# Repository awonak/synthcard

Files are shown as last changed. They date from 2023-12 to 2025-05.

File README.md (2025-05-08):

# SynthCard

Synth Card for Adam Wonak

This synthcard is a circuit inspired by [Hagiwo's](https://www.youtube.com/@HAGIWO) SyncLFO and Bezier Curve, and the [Modulove](https://modulove.io/) MVMNT. I chose this design because of the seemingly endless creative firmware scripts I have written for the [Modulove Sync LFO](https://awonak.github.io/HagiwoModulove/synclfo/), so I wanted to make a business card to highlight this circuit design with some fun tweaks.

This is an iteration of the [SynthCard.com](https://synthcard.com) community from [Benjie Jiao](https://github.com/benjiao). 

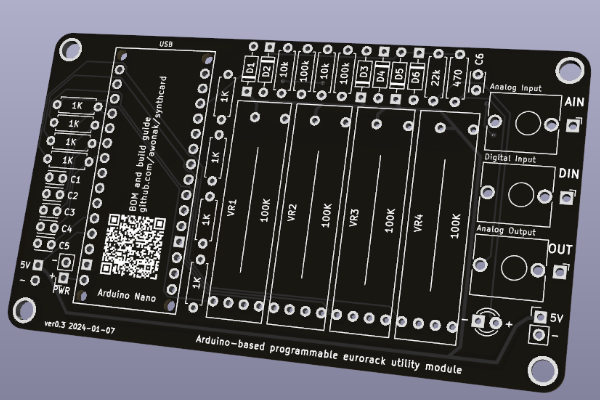
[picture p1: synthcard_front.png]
SynthCard front


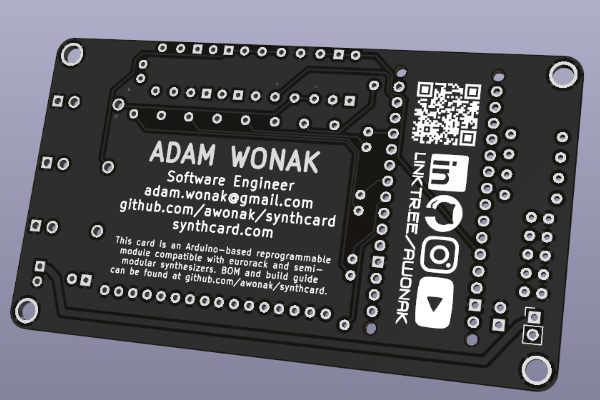
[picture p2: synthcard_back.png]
SynthCard back


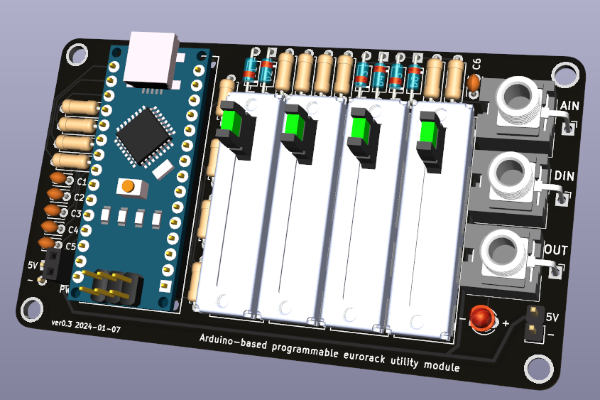
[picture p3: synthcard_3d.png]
SynthCard 3D


## Demo Videos

4 Step Sequencer - https://youtu.be/5_vGYVA8IQ8

ADSR - https://youtu.be/wfQtB7HLKf4

## Synth Card Built by Friends 

[[@benjiaomodular](https://www.youtube.com/@benjiaomodular)] - https://youtube.com/shorts/xnUs8CACG_8

[[@bildpunkt](http://on.soundcloud.com/M9RUxw48PaAXDL477)] - https://youtu.be/3e_gjm9oc40

## Bill of Materials

To assist with assembly, you can use the interactive [ibom.html page](https://htmlpreview.github.io/?https://github.com/awonak/synthcard/blob/main/hardware/bom/ibom.html) to view a part placement guide.

| Reference(s) | Qty | Value | Supplier Link |
|-|-|-|-|
| C1, C2, C3, C4, C5 | 5 | 0.1uF Capacitor  | https://www.mouser.com/ProductDetail/594-K104M15X7RF53L2 |
| C6 | 1 | 4.7uF Capacitor | https://www.mouser.com/ProductDetail/810-FG14X5R1H475KRT6 |
| D1, D2, D3, D4, D5, D6 | 6 | 1N5817 Schottky Diode | https://www.mouser.com/ProductDetail/833-1N5817-TP |
| D7 | 1 | 3MM LED | https://www.mouser.com/ProductDetail/604-WP3A8ID |
| R1, R2, R3, R4 | 4 | 1K Resistor | https://www.mouser.com/ProductDetail/660-MF1-4DCT52R1001F |
| R11, R12, R13, R14 | 4 | 1K Resistor (LED Brightness) | https://www.mouser.com/ProductDetail/660-MF1-4DCT52R1001F |
| R5, R7 | 2 | 10k Resistor | https://www.mouser.com/ProductDetail/660-MF1-4DCT52R1002F |
| R6, R8 | 2 | 100k Resistor | https://www.mouser.com/ProductDetail/660-MF1-4D52R1003F |
| R9 | 1 | 22k Resistor | https://www.mouser.com/ProductDetail/660-MF1-4DCT52R2202F |
| R10 | 1 | 470 Resistor | https://www.mouser.com/ProductDetail/660-MF1-4DCT52R4700F |
| VR1, VR2, VR3, VR4 | 4 | 20MM Slide Potentiometer 100K | https://www.mouser.com/ProductDetail/652-PTL20-15R0-104B1 |
| J3, J4, J5 | 1 | Thonkiconn 3.5mm Mono Jack | https://www.thonk.co.uk/shop/thonkiconn/ |
| A1 | 1 | Arduino Nano | [https://www.amazon.com/...](https://www.amazon.com/LAFVIN-Board-ATmega328P-Micro-Controller-Arduino/dp/B07G99NNXL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) |

## Pinout

| Arduino Pin | Function |
|-|-|
| A0 | Slider 1 Input |
| A1 | Slider 2 Input |
| A2 | Slider 3 Input |
| A3 | Slider 4 Input |
| A7 | Analog Input |
| D3 | Slider 4 LED |
| D5 | Slider 3 LED |
| D6 | Slider 2 LED |
| D9 | Slider 1 LED |
| D10 | Digital Output |
| D11 | Digital Input |

## Code Example

The most basic program we can write for the Synth Card is a Blink program. Using the pin guide above, we can see the digital output is `D10` which has an LED connected to the circuit. We can use this pin to blink the LED. 

```cpp
#define CV_OUT 10  // CV Output with LED

void setup() {
  pinMode(CV_OUT, OUTPUT);
}

void loop() {
  digitalWrite(CV_OUT, HIGH);
  delay(500);
  digitalWrite(CV_OUT, LOW);
  delay(500);
}
```

To test out all of the inputs, outputs, and LEDs, you can flash the [HardwareTest](firmware/HardwareTest/HardwareTest.ino) script.

To see additional example firmware scripts, head over to [firmware](firmware/).

## Hardware Revision History

| Revision | Date | Notes
|-|-|-|
| ver0.3 | 2024-01-07 | - Change: minor silkscreen updates<br> - Change: made 5v trace larger
| ver0.2 | 2023-12-28 | - Fix: CV Output circuit was backwards<br> - Change: Rename capacitor footprint values<br> - Change: Improved LED footprint values<br> - Change: Add linktr.ee and social logos 
| ver0.1 | 2023-12-18 | Initial release

## Enclosure

* Case: [OnShape 3D printer case design](https://cad.onshape.com/documents/56a3cdf5a05401551b0a6543/v/da0e57abf21331cdf97fa6e6/e/f128ee10c6516a251dc2fe2a)
* Cover: [OnShape 3D printer cover design](https://cad.onshape.com/documents/eee74bc148d4d859dd74c709/w/c0c5180a8fda910a15efede6/e/bb4b46e599de372330158219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) (Designed by [BbartokK](https://bbartokk.bandcamp.com/))

## Buy a SynthCard Kit



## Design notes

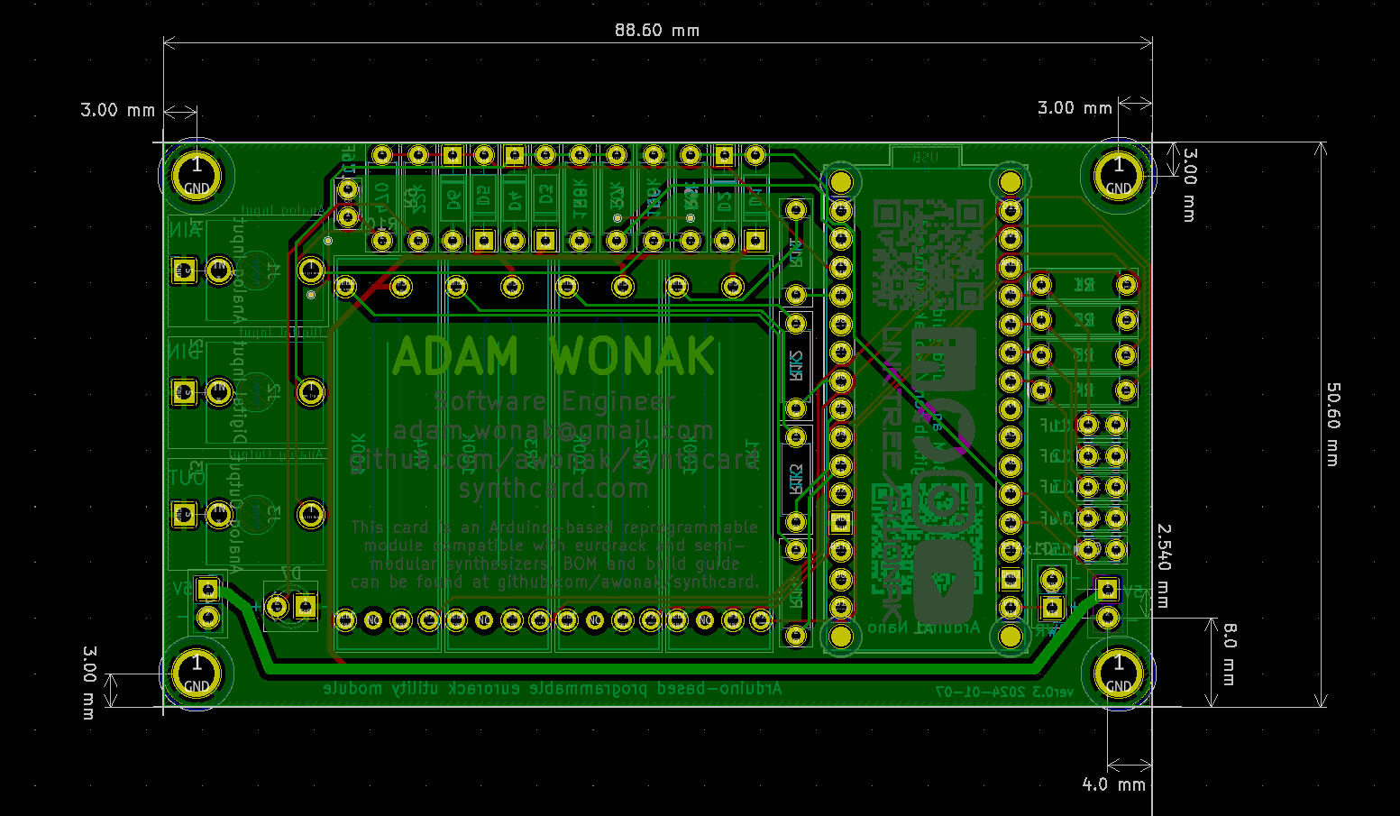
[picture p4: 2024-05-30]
hardware/pcb_view.png

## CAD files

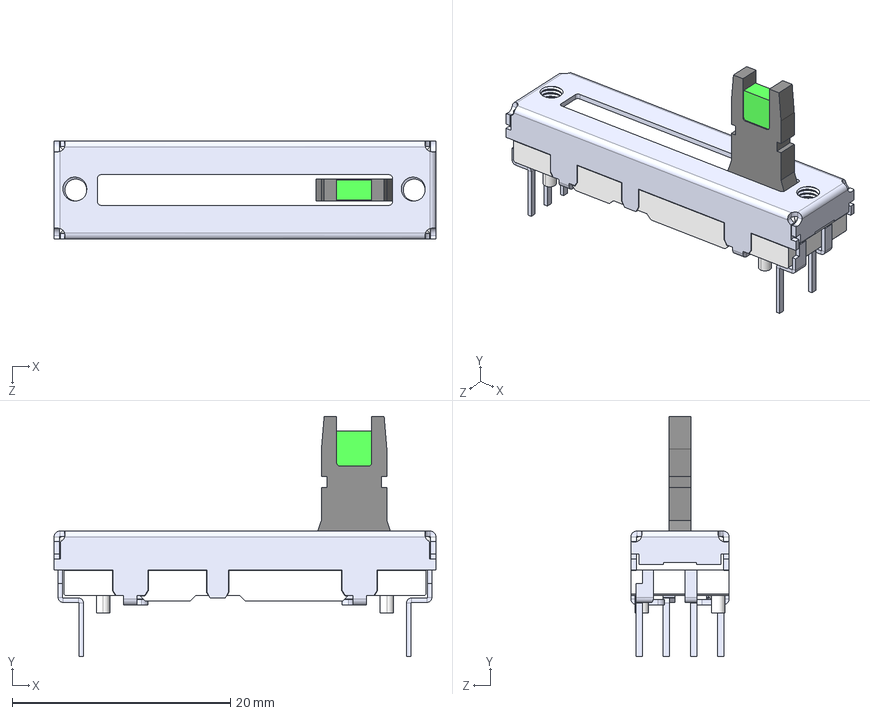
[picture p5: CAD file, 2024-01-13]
hardware/models/PTL20-10R1-102B2.STEP
35.0 x 22.0 x 9.00 mm

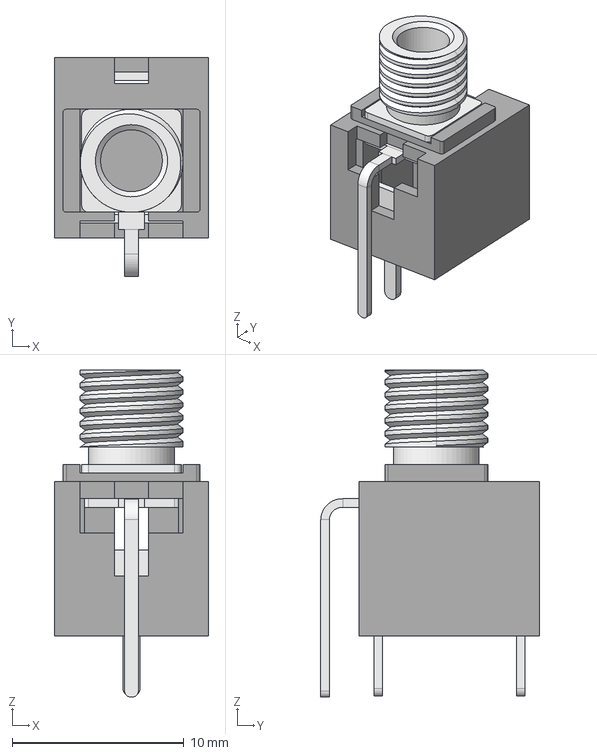
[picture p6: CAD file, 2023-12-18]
hardware/models/PJ398SM.step
9.00 x 12.7 x 19.1 mm

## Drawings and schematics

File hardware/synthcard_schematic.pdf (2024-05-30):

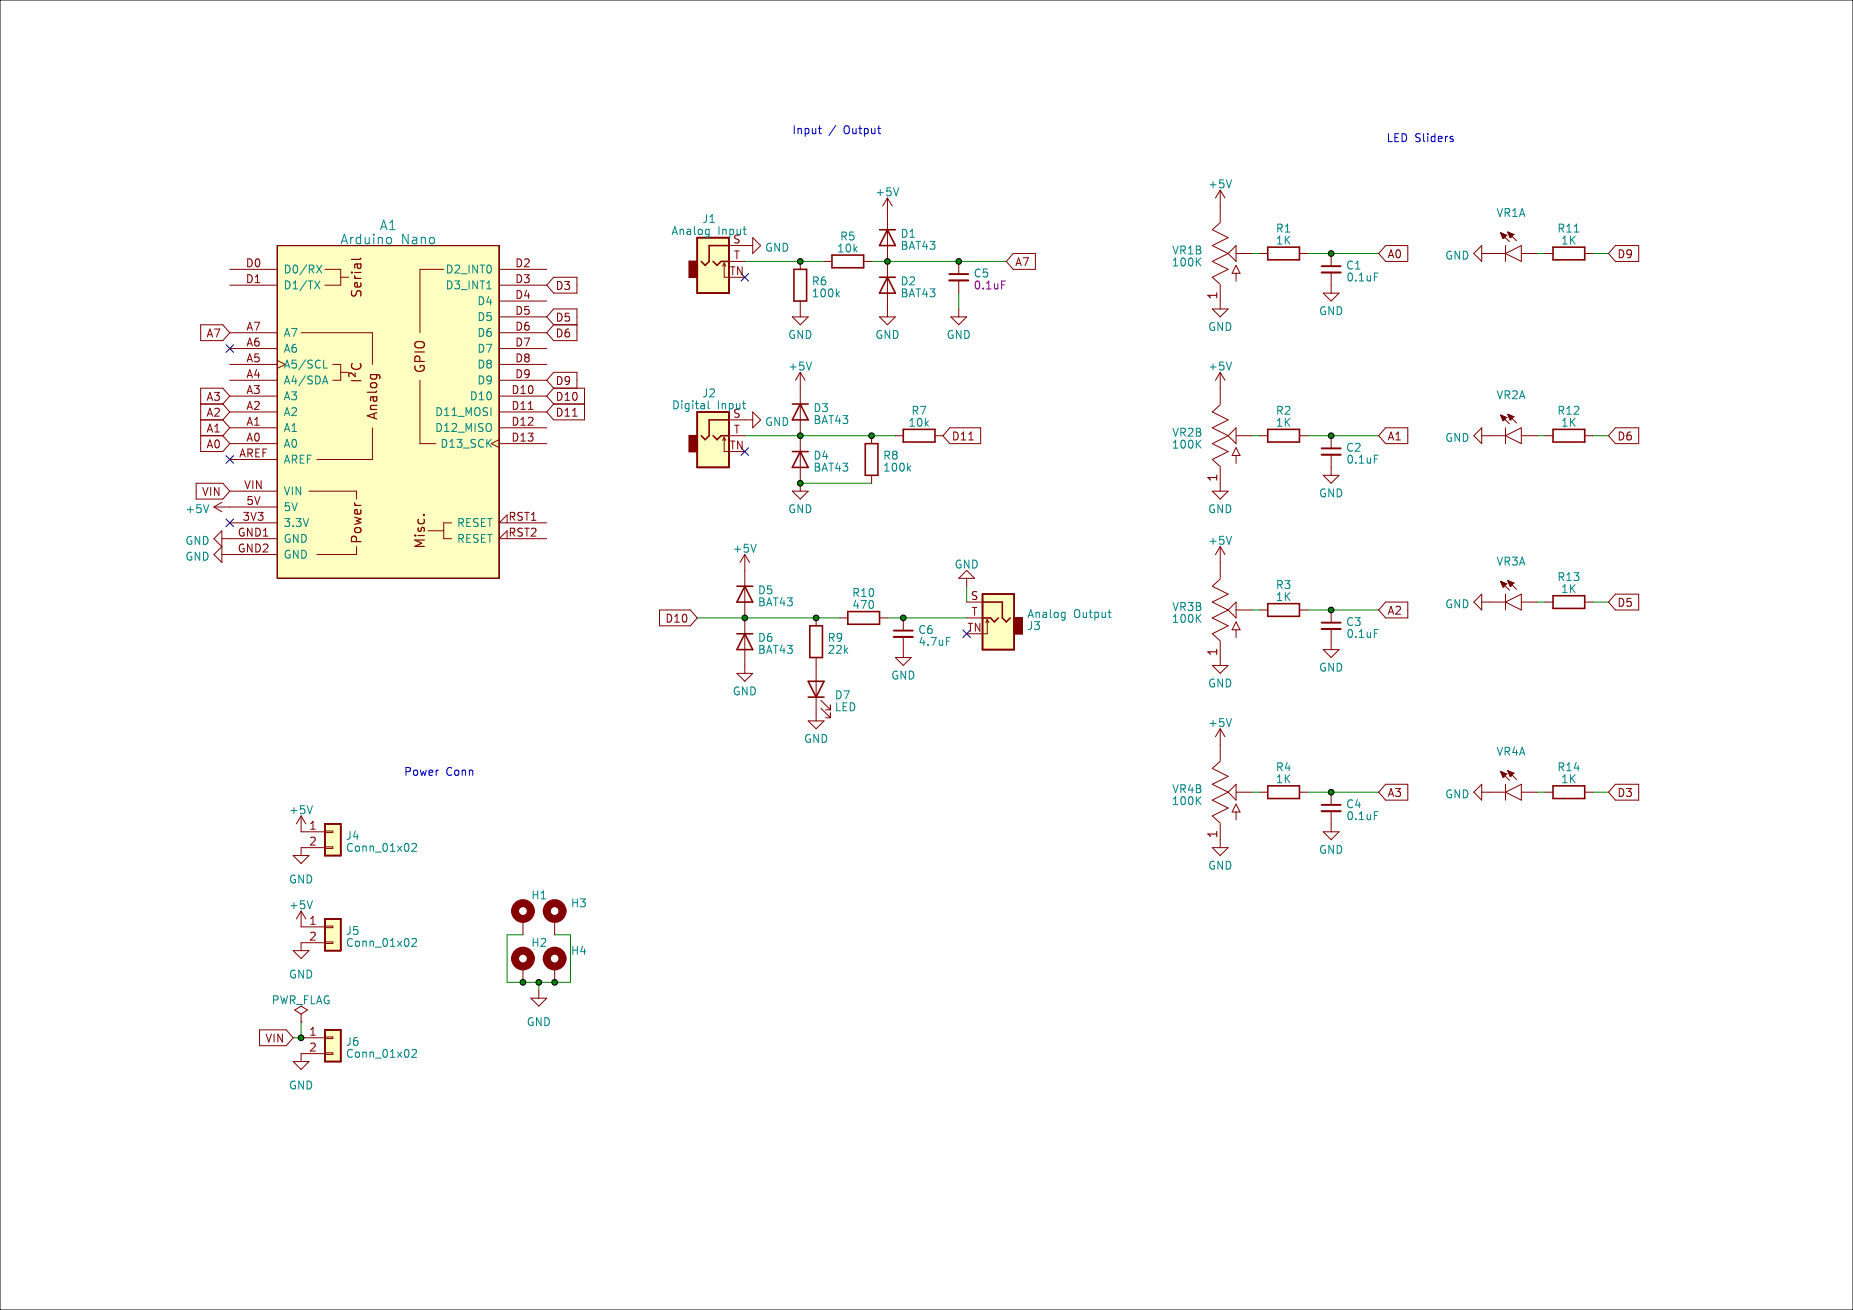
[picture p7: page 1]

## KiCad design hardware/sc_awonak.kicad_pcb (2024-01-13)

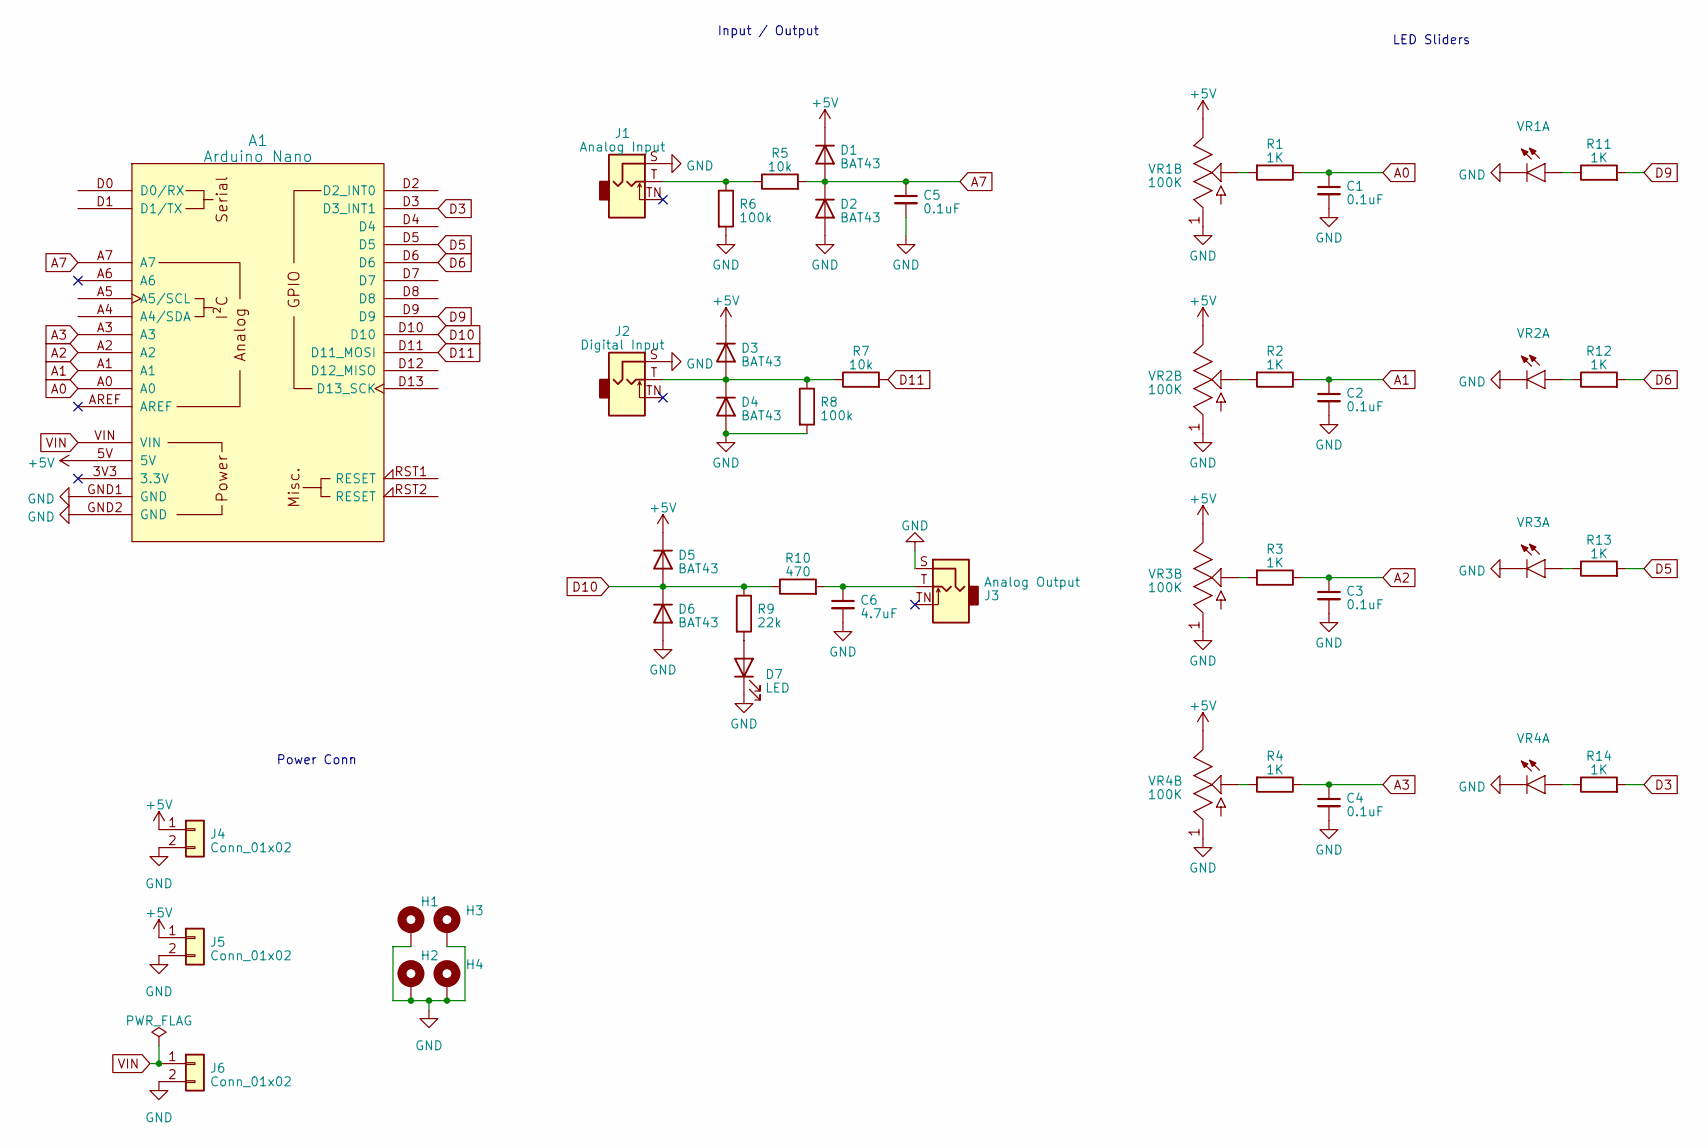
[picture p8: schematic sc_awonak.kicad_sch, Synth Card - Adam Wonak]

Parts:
A1: Arduino Nano; Arduino_Nano_Socket
C1, C2, C3, C4, C5: 0.1uF; C_Disc_D3.0mm_W2.0mm_P2.50mm
C6: 4.7uF; C_Disc_D3.0mm_W2.0mm_P2.50mm
D1, D2, D3, D4, D5, D6: BAT43; D_DO-35_SOD27_P7.62mm_Horizontal
D7: LED; LED_D3.0mm
H1, H2, H3, H4: MountingHole_Pad; MountingHole_3.2mm_M3_Pad
J1: Analog Input; Jack_3.5mm_QingPu_WQP-PJ398SM_Vertical_CircularHoles
J2: Digital Input; Jack_3.5mm_QingPu_WQP-PJ398SM_Vertical_CircularHoles
J3: Analog Output; Jack_3.5mm_QingPu_WQP-PJ398SM_Vertical_CircularHoles
J4, J5, J6: Conn_01x02; PinHeader_1x02_P2.54mm_Horizontal
R1, R2, R3, R4, R11, R12, R13, R14: 1K; R_Axial_DIN0207_L6.3mm_D2.5mm_P7.62mm_Horizontal
R5, R7: 10k; R_Axial_DIN0207_L6.3mm_D2.5mm_P7.62mm_Horizontal
R6, R8: 100k; R_Axial_DIN0207_L6.3mm_D2.5mm_P7.62mm_Horizontal
R9: 22k; R_Axial_DIN0207_L6.3mm_D2.5mm_P7.62mm_Horizontal
R10: 470; R_Axial_DIN0207_L6.3mm_D2.5mm_P7.62mm_Horizontal
VR1, VR2, VR3, VR4: 100K; Pot_Slider_LED_20mm_RA2045F

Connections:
+5V: A1.5V, D1.1 (K), D3.1 (K), D5.1 (K), J4.1, J5.1, VR1.P3 (3), VR2.P3 (3), VR3.P3 (3), VR4.P3 (3)
A0: A1.A0, C1.1, R1.1
A1: A1.A1, C2.1, R2.1
A2: A1.A2, C3.1, R3.1
A3: A1.A3, C4.1, R4.1
A7: A1.A7, C5.1, D1.2 (A), D2.1 (K), R5.2
D3: A1.D3 (D3_INT1), R14.2
D5: A1.D5, R13.2
D6: A1.D6, R12.2
D9: A1.D9, R11.2
D10: A1.D10, D5.2 (A), D6.1 (K), R9.1, R10.1
D11: A1.D11 (D11_MOSI), R7.2
GND: A1.GND1 (GND), A1.GND2 (GND), C1.2, C2.2, C3.2, C4.2, C5.2, C6.2, D2.2 (A), D4.2 (A), D6.2 (A), D7.1 (K), H1.1, H2.1, H3.1, H4.1, J1.S, J2.S, J3.S, J4.2, J5.2, J6.2, R6.2, R8.2, VR1.LEDC (C), VR1.P1 (1), VR2.LEDC (C), VR2.P1 (1), VR3.LEDC (C), VR3.P1 (1), VR4.LEDC (C), VR4.P1 (1)
unnamed: C6.1, J3.T, R10.2
unnamed: D3.2 (A), D4.1 (K), J2.T, R7.1, R8.1
unnamed: D7.2 (A), R9.2
unnamed: J1.T, R5.1, R6.1
unnamed: R11.1, VR1.LEDA (A)
unnamed: R1.2, VR1.P2 (2)
unnamed: R12.1, VR2.LEDA (A)
unnamed: R2.2, VR2.P2 (2)
unnamed: R13.1, VR3.LEDA (A)
unnamed: R3.2, VR3.P2 (2)
unnamed: R14.1, VR4.LEDA (A)
unnamed: R4.2, VR4.P2 (2)
VIN: A1.VIN, J6.1

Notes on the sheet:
Input / Output
LED Sliders
Power Conn

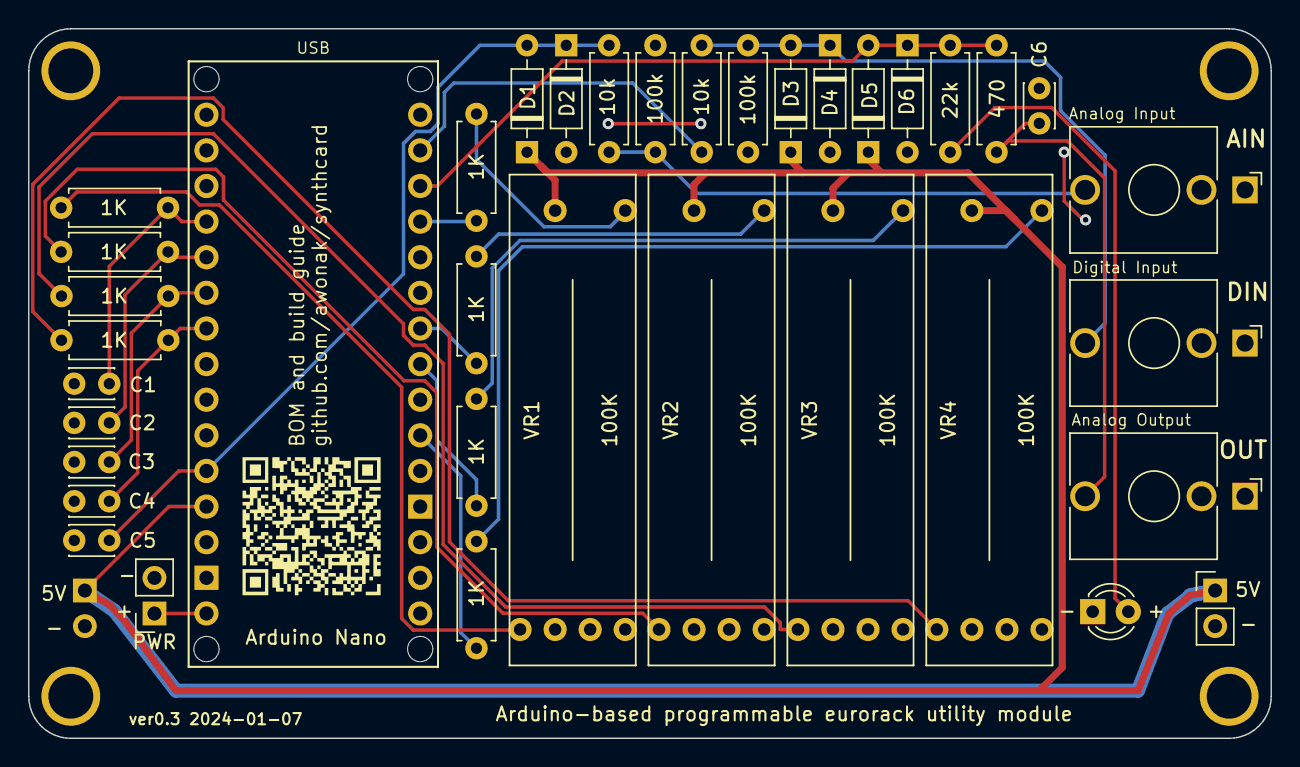
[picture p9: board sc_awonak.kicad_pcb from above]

Board: 2 copper layers, 88.6 x 50.6 mm, 42 parts (1 on the bottom side), 26 nets.

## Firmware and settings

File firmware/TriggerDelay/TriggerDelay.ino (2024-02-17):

// GPIO Pin mapping.
#define P1 A0  // Trigger Delay
#define P2 A1  // Attack Slope
#define P3 A2  // Gate Duration
#define P4 A3  // Release Slope
#define SLIDER_COUNT 4

#define LED1 9  // Slider LED 1
#define LED2 6  // Slider LED 2
#define LED3 5  // Slider LED 3
#define LED4 3  // Slider LED 4

#define ANALOG_IN 21   // Analog Input
#define DIGITAL_IN 11  // Trigger Input to advance step
#define CV_OUT 10      // CV Output for current step

// Slider & LED pin arrays to support looping over led sliders.
const uint8_t SLIDER_PIN[SLIDER_COUNT] = {P1, P2, P3, P4};
const uint8_t LED_PIN[SLIDER_COUNT] = {LED1, LED2, LED3, LED4};

// Conversion calculations: Arduino 5v pin will only output 4.6v when powered by
// USB.
const float VREF = 4.6 / 1023.0;

// Global state variables.
uint8_t din = 0;  // Digital input read value.
uint8_t old_din = 0;
int slider[SLIDER_COUNT];  // Hold the current slider value in an array of
                           // sliders.
float R;                   // R holds the linear to exponential conversion factor value.

enum Stage {
    DELAY,
    ATTACK,
    GATE,
    RELEASE,
    WAIT,
};
Stage stage = WAIT;

// Script state.
unsigned long trig_start;
int trig_delay;
int trig_duration;
int attack_slope;
int release_slope;
int attack_count;
int release_count;
int counter;
int output;

void setup() {
    pinMode(ANALOG_IN, INPUT);
    pinMode(DIGITAL_IN, INPUT);
    pinMode(CV_OUT, OUTPUT);
    pinMode(P1, INPUT);
    pinMode(P2, INPUT);
    pinMode(P3, INPUT);
    pinMode(P4, INPUT);
    pinMode(LED1, OUTPUT);
    pinMode(LED2, OUTPUT);
    pinMode(LED3, OUTPUT);
    pinMode(LED4, OUTPUT);

    // Register setting for high frequency PWM.
    TCCR1A = 0b00100001;
    TCCR1B = 0b00100001;

    // Calculate the linear to exponential R value (only needs to be done once at setup).
    R = (1023 * log10(2)) / (log10(255));
}

void loop() {
    // Read all inputs.
    old_din = din;
    din = digitalRead(DIGITAL_IN);
    for (int i = 0; i < SLIDER_COUNT; i++) {
        slider[i] = analogRead(SLIDER_PIN[i]);
    }

    // Set LED Brightness.
    for (int i = 0; i < SLIDER_COUNT; i++) {
        analogWrite(LED_PIN[i], brightness(slider[i]));
    }

    // Detect if a new trigger has been received.
    if (old_din == 0 && din == 1) {
        // Read the trigger delay and duration.
        trig_delay = map(slider[0], 0, 1023, 0, 2000);
        trig_duration = map(slider[2], 0, 1023, 20, 2000);
        trig_start = millis();

        // Calculate the exponential slope value.
        attack_count = slider[1];
        release_count = slider[3];
        attack_slope = (attack_count * log10(2)) / log10(255);
        release_slope = (release_count * log10(2)) / log10(255);

        stage = DELAY;
        output = 0;
        counter = 1;
    }

    switch (stage) {
        case DELAY:
            if (millis() > trig_start + trig_delay) {
                stage = ATTACK;
            }
            break;
        case ATTACK:
            if (counter >= attack_count) {
                stage = GATE;
                trig_start = millis();
                counter = release_count;
            } else {
                output = min(pow(2, (float(counter) / float(attack_slope))), 255);
                counter = min(counter++, attack_count);
            }
            break;
        case GATE:
            output = 255;
            if (millis() > trig_start + trig_duration) {
                stage = RELEASE;
            }
            break;
        case RELEASE:
            if (counter == 0) {
                stage = WAIT;
                output = 0;
            } else {
                output = min(pow(2, float(counter) / float(release_slope)), 255);
                if (counter > 0) counter--;
            }
            break;
        case WAIT:
            break;
    }

    // Set output voltage.
    analogWrite(CV_OUT, output);
}

// Convert a linear value to its exponential compliment for led visual correction.
int brightness(int v) { return (v > 32) ? pow(2, (v / R)) : 0; }

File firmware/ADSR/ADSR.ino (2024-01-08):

// GPIO Pin mapping.
#define S1 A0  // Slider Potentiometer 1
#define S2 A1  // Slider Potentiometer 2
#define S3 A2  // Slider Potentiometer 3
#define S4 A3  // Slider Potentiometer 4
#define SLIDER_COUNT 4

#define LED1 9  // Slider LED 1
#define LED2 6  // Slider LED 2
#define LED3 5  // Slider LED 3
#define LED4 3  // Slider LED 4

#define ANALOG_IN A7   // Analog Input
#define DIGITAL_IN 11  // Trigger Input to advance step
#define CV_OUT 10      // CV Output for current step

// Slider & LED pin arrays to support looping over led sliders.
const uint8_t SLIDER_PIN[SLIDER_COUNT] = {S1, S2, S3, S4};
const uint8_t LED_PIN[SLIDER_COUNT] = {LED1, LED2, LED3, LED4};

// Conversion calculations: Arduino 5v pin will only output 4.6v when powered by
// USB.
const float VREF = 4.6 / 1023.0;

// Global state variables.
int ain = 0;  // Raw cv read from pot for current step
int old_ain = 0;
uint8_t din = 0;  // Digital input read value.
uint8_t old_din = 0;
int slider[SLIDER_COUNT];  // Hold the current slider value in an array of
                           // sliders.
float R;  // R holds the linear to exponential conversion factor value.

// Script state variables.
const byte top = 255;  // Envelope state max value
byte val = 0;          // Envelope state value
int time = 0;          // Envelope delay time between incremental change
int sustain = 0;       // Sustain value;

enum Stage { ATTACK, DECAY, SUSTAIN, RELEASE };
Stage stage = ATTACK;

void setup() {
  pinMode(ANALOG_IN, INPUT);
  pinMode(DIGITAL_IN, INPUT);
  pinMode(CV_OUT, OUTPUT);
  pinMode(S1, INPUT);
  pinMode(S2, INPUT);
  pinMode(S3, INPUT);
  pinMode(S4, INPUT);
  pinMode(LED1, OUTPUT);
  pinMode(LED2, OUTPUT);
  pinMode(LED3, OUTPUT);
  pinMode(LED4, OUTPUT);

  // Register setting for high frequency PWM.
  TCCR1A = 0b00100001;
  TCCR1B = 0b00100001;

  // Calculate the R variable (only needs to be done once at setup).
  R = (1023 * log10(2)) / (log10(255));

  delay(100);
}

void loop() {
  // Check gate input.
  old_din = din;
  din = digitalRead(DIGITAL_IN);

  // Detect if gate has just opened and begin envelope attack.
  if (old_din == 0 && din == 1) {
    stage = ATTACK;
    val = 0;
  }

  // Detect if gate has just closed and begin the release envelope.
  if (old_din == 1 && din == 0) {
    stage = RELEASE;
  }

  // Advance the cv value for the current envelope stage according to the
  // related stage knob position.
  switch (stage) {
    case ATTACK:
      // At minimum attack levels, traverse the curve at a faster rate than
      // default.
      val += analogRead(S1) == 0 ? min(top - val, 10) : 1;

      if (val >= top) {
        stage = DECAY;
      }
      break;

    case DECAY:
      // Decrease the envelope value if it's still falling.
      if (val > 0) {
        // At minimum release levels, traverse the curve at a faster rate than
        // default.
        val -= analogRead(S2) == 0 ? min(val, 10) : 1;
      }

      // Check if the falling decay envelope has reached sustain level.
      sustain = min(map(analogRead(S3), 0, 1023, 0, top), val);
      if (val <= sustain) {
        stage = SUSTAIN;
      }
      break;

    case SUSTAIN:
      val = map(analogRead(S3), 0, 1023, 0, top);
      break;

    case RELEASE:
      // Decrease the envelope value if it's still falling.
      if (val > 0) {
        // At minimum release levels, traverse the curve at a faster rate than
        // default.
        val -= analogRead(S4) == 0 ? min(val, 10) : 1;
      }
      break;
  }

  // Attack / Decay / Release incremental delay time.
  switch (stage) {
    case ATTACK:
      time = analogRead(S1);
      break;
    case DECAY:
      time = analogRead(S2);
      break;
    case SUSTAIN:
      time = 1000;  // Default time for Sustain.
      break;
    case RELEASE:
      time = analogRead(S4);
      break;
  }

  // Attack / Decay / Release stage LED indicator.
  for (int i = 0; i < SLIDER_COUNT; i++) {
    analogWrite(LED_PIN[i], 0);
  }
  switch (stage) {
    case ATTACK:
      analogWrite(LED_PIN[0], val);
      break;
    case DECAY:
      analogWrite(LED_PIN[1], val);
      break;
    case SUSTAIN:
      analogWrite(LED_PIN[2], val);
      break;
    case RELEASE:
      analogWrite(LED_PIN[3], val);
      break;
  }

  // Write envelope CV output
  analogWrite(CV_OUT, val);

  // Short sleep duration before advancing to the next step in the curve table.
  delayMicroseconds(time * 10);
}

// Convert a linear value to its exponential compliment for led visual
// correction.
int brightness(int v) { return (v > 32) ? pow(2, (v / R)) : 0; }

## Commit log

2023-12-18 More revision updates and add preview image
    [sc_awonak.kicad_pcb, sc_awonak.kicad_sch]
2023-12-18 Added 3d rendering, schematic PDF, and more pcb revisions.
    [sc_awonak.kicad_pcb, sc_awonak.kicad_sch]
2023-12-19 Added BOM to README
    [sc_awonak.kicad_sch]
2023-12-19 Add ibom and update gitignore
    [sc_awonak.kicad_pcb, sc_awonak.kicad_sch]
2023-12-20 Update README.md
    Fix resistor links for consistency. Add Arduino Pinout.
2023-12-29 rename schematic file
2023-12-29 hardware revision ver0.2
    [sc_awonak.kicad_pcb, sc_awonak.kicad_sch]
2024-01-07 update a few silkscreen details. larger 5v trace. update ibom.
    [sc_awonak.kicad_pcb, sc_awonak.kicad_sch]
2024-01-13 rename kicad project folder from sc_awonak to hardware.
    [PJ398SM.step, sc_awonak.kicad_pcb, sc_awonak.kicad_sch]
2024-01-13 Update rendering images to match current revision. Add demo video.
    [PTL20-10R1-102B2.STEP]
2024-01-13 update 3d model of pcb editor view
    [sc_awonak.kicad_pcb]
2024-02-16 Add enclosure link to readme
2025-05-08 Update README.md
    Added link to a 3D Printable enclosure lid designed by BbartokK
